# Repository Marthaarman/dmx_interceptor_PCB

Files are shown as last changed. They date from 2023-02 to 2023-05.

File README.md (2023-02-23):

# PCB DMX Interceptor
A PCB designed for the dmx-transceiver library, to which an extra switch can be connected.
https://github.com/Marthaarman/dmx-transceiver

schematics: https://github.com/Marthaarman/dmx_interceptor_PCB/blob/main/dmx_interceptor.pdf

## components
- 2x debo rs485 TTL - https://www.reichelt.de/de/en/developer-boards-ttl-to-rs485-max485-debo-rs485-ttl-p282703.html
- 1x arduino pro mini - https://www.digikey.nl/nl/products/detail/sparkfun-electronics/DEV-11113/5140820
- 2x 3 pin screw terminal - https://www.digikey.nl/nl/products/detail/cui-devices/TB009-508-03BE/10064152
- 2x 2 pin screw terminal - https://www.digikey.nl/nl/products/detail/cui-devices/TB009-508-02BE/10064151
- 1x 10k resistor 0603 (1608 metric) - https://www.digikey.nl/nl/products/detail/stackpole-electronics-inc/RNCP0603FTD10K0/2240139
- 2x 12 pin header female - https://www.digikey.nl/nl/products/detail/adam-tech/RS1-12-G/9832041
- 4x 4 pin header female - https://www.digikey.nl/nl/products/detail/adam-tech/RS1-04-G/9829303
- 2x 12 pin header male - https://www.digikey.nl/nl/products/detail/adam-tech/PH1-12-UA/9830395

Depending on the FT232RL you bought you need either male or female:
- 1x female 5 pin header for ft232rl adapter: https://www.digikey.nl/nl/products/detail/adam-tech/RS1-05-G/9832046
- 1x male 5 pin header for ft232rl adapter: https://www.digikey.nl/nl/products/detail/adam-tech/PH1RB-05-UA/9831540

### 1 time requirement: 	
- 1x FT232RL USB TTL Serial Port Adapter 3.3v/5V - https://www.digikey.nl/nl/products/detail/sparkfun-electronics/KIT-18290/14552423

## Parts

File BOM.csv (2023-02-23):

Reference | Value | Footprint | Datasheet | MANUFACTURER | MAXIMUM_PACKAGE_HEIGHT | MPN | Manufacturer | Manufacturer Part Link | PARTREV | Resistance | STANDARD | Qty
J1, J2 | TB010-508-02BE | dmx_interceptor:CUI_TB010-508-02BE |  | CUI |  | TB010-508-02BE |  |  |  |  | Manufacturer Recommendations | 2
J3, J4 | TB004-508-03BE | dmx_interceptor:CUI_TB004-508-03BE |  | CUI |  | TB004-508-03BE |  |  |  |  | Manufacturer Recommendations | 2
mod1, mod2 | max485_to_RS485 | dmx_interceptor:max485_to_rs485 |  |  |  |  |  |  |  |  |  | 2
R1 | R-generic | dmx_interceptor:smd_0603_1608-Metric | ~ |  |  | RNCP0603FTD10K0 |  |  |  | 10k |  | 1
U1 | ARDUINO_PRO_MINI | dmx_interceptor:MODULE_ARDUINO_PRO_MINI |  | SparkFun Electronics | N/A | DEV-11113 |  |  | N/A |  | Manufacturer Recommendations | 1

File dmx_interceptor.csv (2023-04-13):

Item | Qty | Reference(s) | Value | LibPart | Footprint | Datasheet | DNP | MANUFACTURER | MAXIMUM_PACKAGE_HEIGHT | MPN | PARTREV | Resistance | STANDARD | mnp | mpn
1 | 2 | J1, J2 | TB010-508-02BE | dmx_interceptor:TB010-508-02BE | dmx_interceptor:CUI_TB010-508-02BE |  |  | CUI |  | TB010-508-02BE |  |  | Manufacturer Recommendations | TB010-508-02BE
2 | 2 | J3, J4 | TB004-508-03BE | dmx_interceptor:TB004-508-03BE | dmx_interceptor:CUI_TB004-508-03BE |  |  | CUI |  | TB004-508-03BE |  |  | Manufacturer Recommendations |  | TB004-508-03BE
3 | 2 | mod1, mod2 | max485_to_RS485 | dmx_interceptor:max485_to_RS485 | dmx_interceptor:max485_to_rs485
4 | 1 | R1 | R-generic | dmx_interceptor:R-generic | dmx_interceptor:R_THT | ~ |  |  |  | RNF14FTD10K0 |  | 10k
5 | 1 | U1 | ARDUINO_PRO_MINI | dmx_interceptor:ARDUINO_PRO_MINI | dmx_interceptor:MODULE_ARDUINO_PRO_MINI |  |  | SparkFun Electronics | N/A | DEV-11113 | N/A |  | Manufacturer Recommendations |  | DEV-11113

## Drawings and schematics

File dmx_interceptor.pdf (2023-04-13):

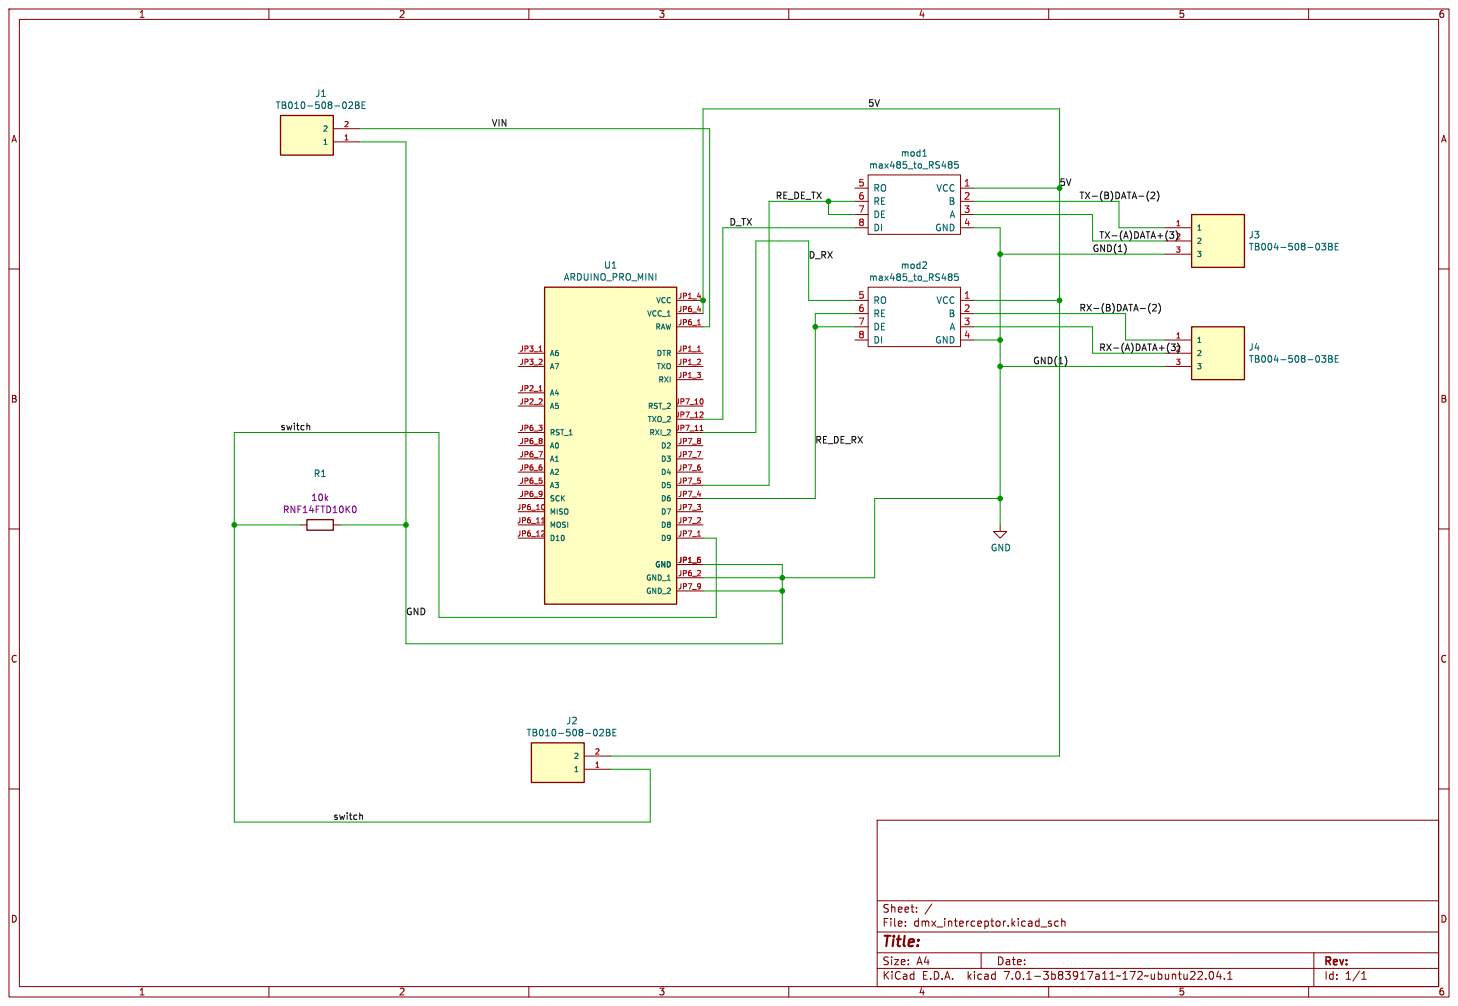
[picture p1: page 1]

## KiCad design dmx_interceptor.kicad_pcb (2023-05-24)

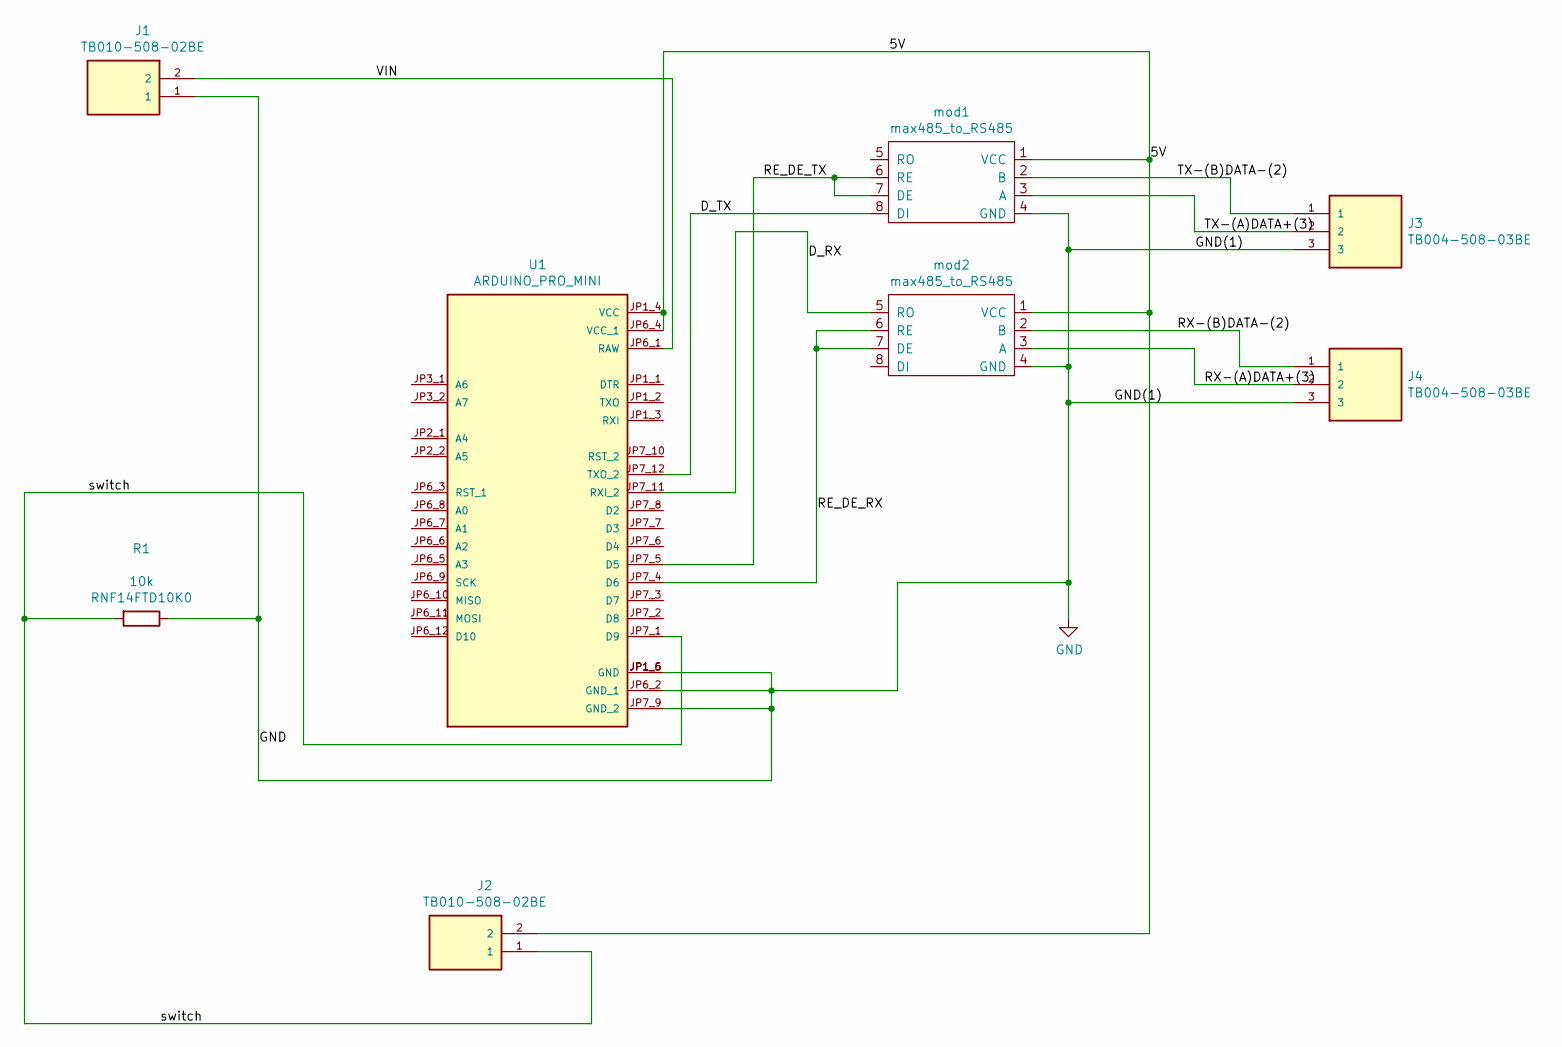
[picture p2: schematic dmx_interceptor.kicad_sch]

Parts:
J1, J2: TB010-508-02BE; CUI_TB010-508-02BE; MPN TB010-508-02BE
J3, J4: TB004-508-03BE; CUI_TB004-508-03BE; mpn TB004-508-03BE
R1: R-generic; R_THT; MPN RNF14FTD10K0
U1: ARDUINO_PRO_MINI; MODULE_ARDUINO_PRO_MINI; PARTREV N/A
mod1, mod2: max485_to_RS485; max485_to_rs485

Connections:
/5V: J2.2, U1.JP1_4 (VCC), U1.JP6_4 (VCC_1), mod1.1 (VCC), mod2.1 (VCC)
/D_RX: U1.JP7_11 (RXI_2), mod2.5 (RO)
/D_TX: U1.JP7_12 (TXO_2), mod1.8 (DI)
/RE_DE_RX: U1.JP7_4 (D6), mod2.6 (RE), mod2.7 (DE)
/RE_DE_TX: U1.JP7_5 (D5), mod1.6 (RE), mod1.7 (DE)
/RX-(A)DATA+(3): J4.2, mod2.3 (A)
/RX-(B)DATA-(2): J4.1, mod2.2 (B)
/TX-(A)DATA+(3): J3.2, mod1.3 (A)
/TX-(B)DATA-(2): J3.1, mod1.2 (B)
/VIN: J1.2, U1.JP6_1 (RAW)
/switch: J2.1, R1.2, U1.JP7_1 (D9)
GND: J1.1, J3.3, J4.3, R1.1, U1.JP1_5 (GND), U1.JP1_6 (GND), U1.JP6_2 (GND_1), U1.JP7_9 (GND_2), mod1.4 (GND), mod2.4 (GND)

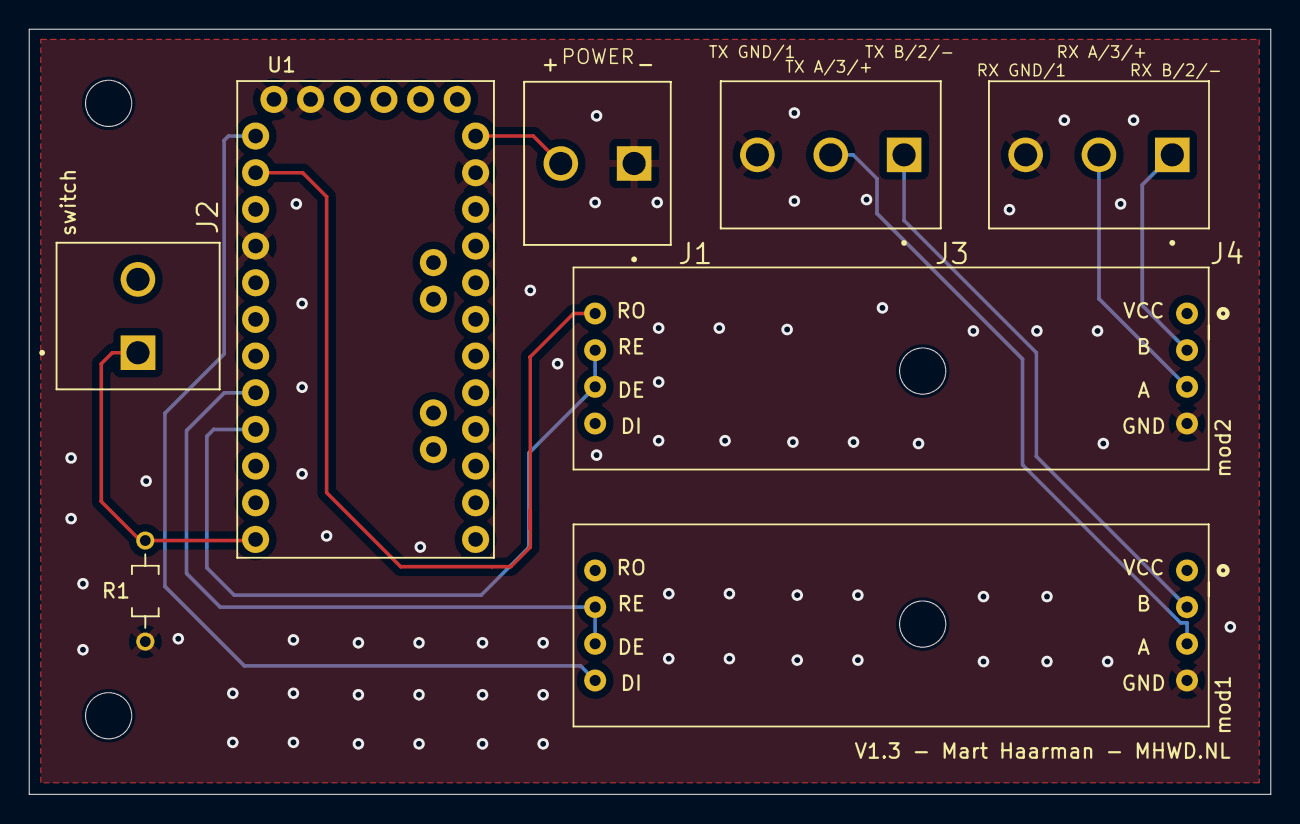
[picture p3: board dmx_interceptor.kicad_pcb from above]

Board: 4 copper layers, 86.0 x 53.0 mm, 8 parts (0 on the bottom side), 12 nets.

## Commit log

2023-02-21 fix all refs
    [dmx_interceptor.csv, dmx_interceptor.kicad_pcb, dmx_interceptor.kicad_sch]
2023-02-23 output files for ordering & pcb fix
    [BOM.csv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]
2023-04-13 change resistor to throughole
    [dmx_interceptor-B_Mask.gbs, dmx_interceptor-B_Paste.gbp, dmx_interceptor-B_Silkscreen.gbo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]
2023-05-24 added 4 mounting holes
    [dmx_interceptor-B_Mask.gbs, dmx_interceptor-B_Paste.gbp, dmx_interceptor-B_Silkscreen.gbo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]
